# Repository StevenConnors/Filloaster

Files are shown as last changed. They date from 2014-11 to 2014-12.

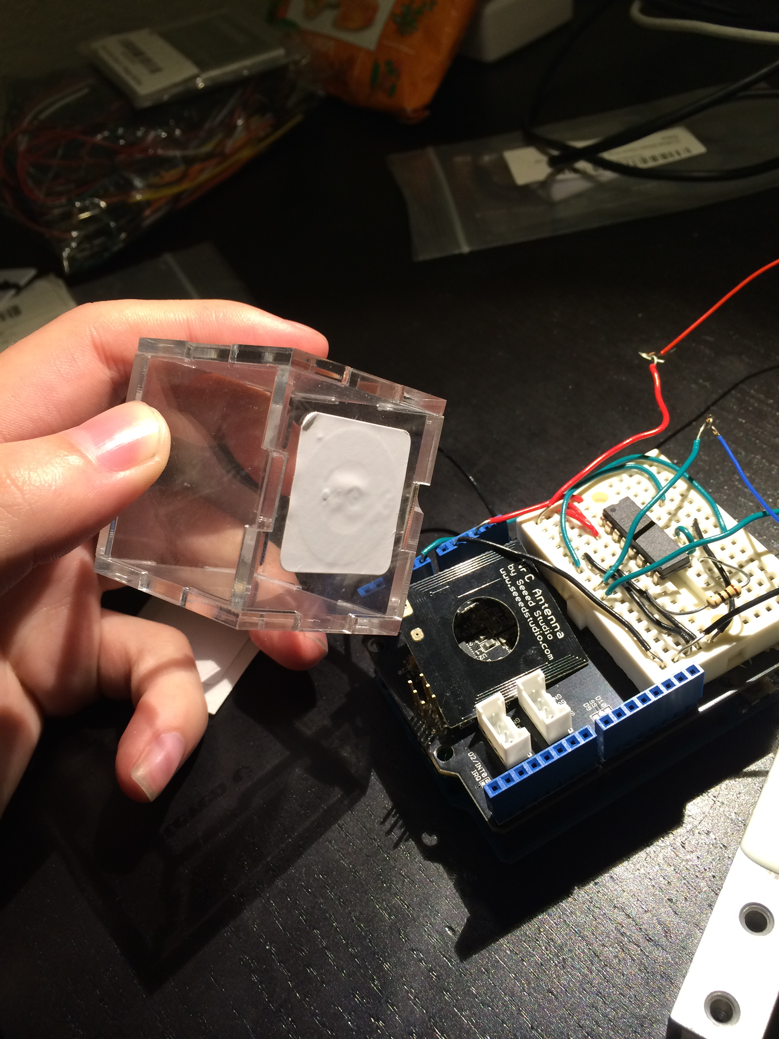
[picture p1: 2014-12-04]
Documents/Photos/prototype1.jpg

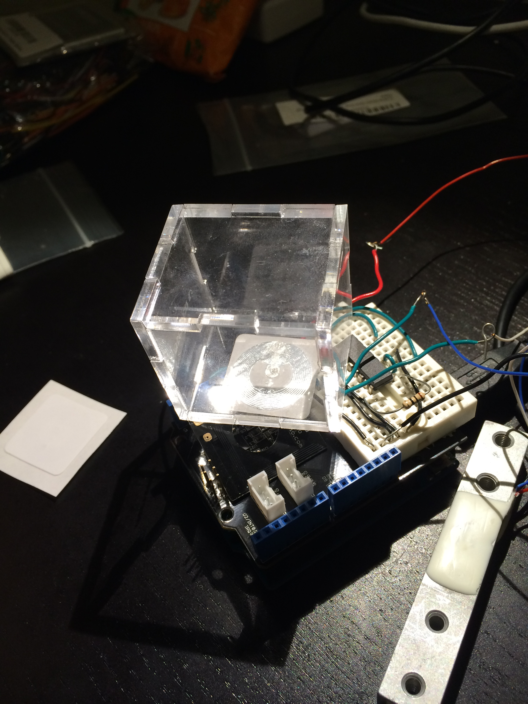
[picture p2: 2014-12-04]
Documents/Photos/IMG_3669.JPG

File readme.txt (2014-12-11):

Filloaster - A smart coaster that keeps you always filled.

Main website: steven77723.github.io/Filloaster

Concept:

List of Files and their Description:

Main Folder: Consists of various folders and files. The files are crucial to the
project as these initiate the Node server and execute the routing and the 
starting of web sockets for the browser and the Arduino. A detailed description
of each file can be found at the top of each file respectively. However, to give
a brief over view of how it works, the user calles index.js. Then index.js
creates a routing method for each url which is mapped to a file in the project
folder. Then server.js is called and run, where it creates sockets to the 
Arduino and the browser. Server.js handles all computationally heavy tasks while
the other folders send flags to signal such tasks.

Pages Folder: Mainly consists of html files which are used when deploying the 
server. However, there are three that we'd like to focus on. 

The first is the main html file, main.html. This file is the website that we
first displayed during the demo and we've placed a lot of emphasis on design. 
This page can be seen at steven77723.github.io/Filloaster. 

The second html file that needs emphasis is restaurant.html. We designed this
page so that it resembles a live restaurant with customers and seats. For the 
sake of the demo, we only displayed a change in color of seating with respect
to the state of the glass (needs refill / not). However, the color can also be
white if there is nobody at the table. This page uses SocketIO to receive the 
information obtained from the Filloaster (Arduino).

The most important page in terms of the demo is interface.html. This file allows
us to visually see the information sent via the Arduino, such as the amount of
liquid in the glass, the weight of the full / empty / current glass, the type of
drink that is in the glass, and the state of the Filloaster. 

ArduinoCode Folder: Has one file, filloster.ino that handles everything related
to the Arduino. This file receives information regarding the weight of the
glass, the state of Filloaster, the NFC information (glass type and phone 
number), and sends flags to server.js where more computationally heavy items are
executed. The code implements a simple finite state machine which makes the code
cleaner and easier to read and understand. 

Case Design: Initially we we're going to 3d print a casing for the Arduino for
aesthetics reasons, but due to the restriction that the force of the glass needs
to be pressed directly in the center of the we decided not to print it for the 
demo. However within this folder is the 3d model of the casing.

Documents: Included are the documents / images / slides for the demo. We've also
included a circuitry diagram which people can use if they would like to recreate
Filloaster with their own hands. 

Node_Modules Folder: Simply put, the modules we used: socketio, serial port, and
Twilio.

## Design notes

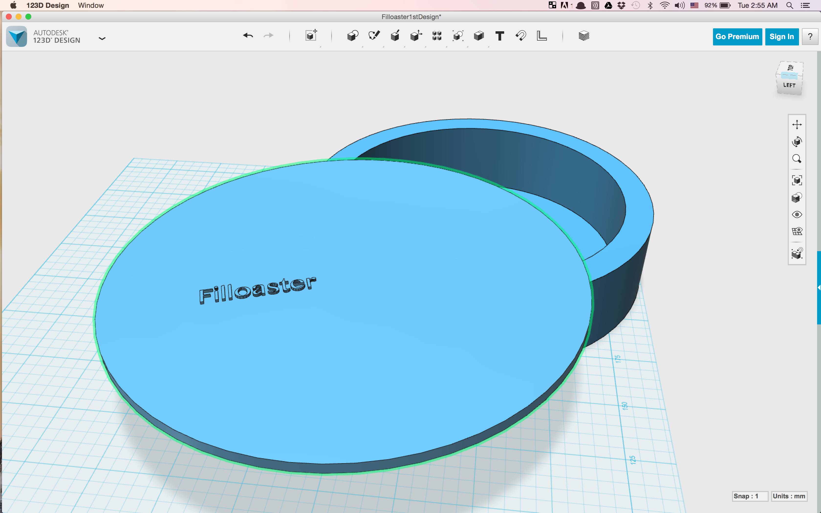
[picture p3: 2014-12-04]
Documents/Photos/filloasterdesign.png

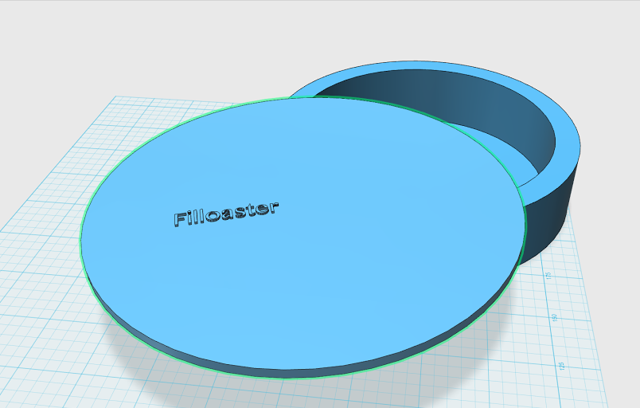
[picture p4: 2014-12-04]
bootstrap/img/filloasterdesign.png

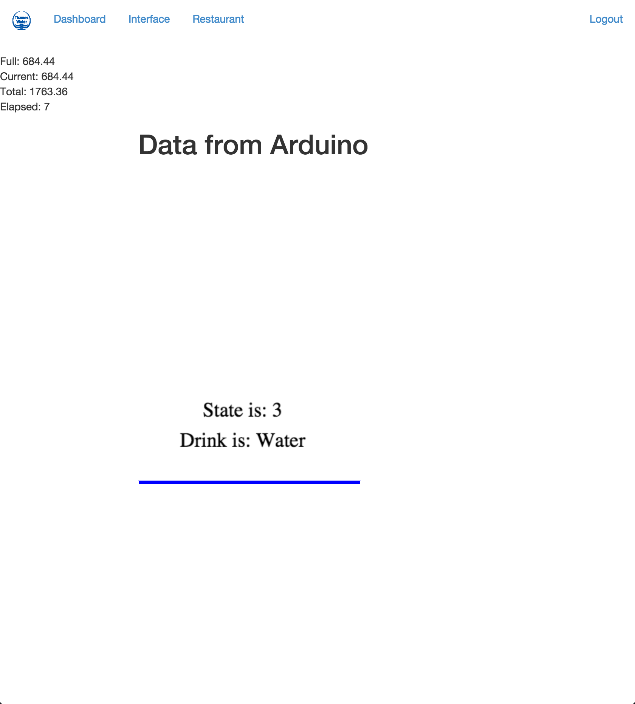
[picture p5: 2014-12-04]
Documents/Photos/Screen Shot 2014-12-03 at 12.55.47 AM.png

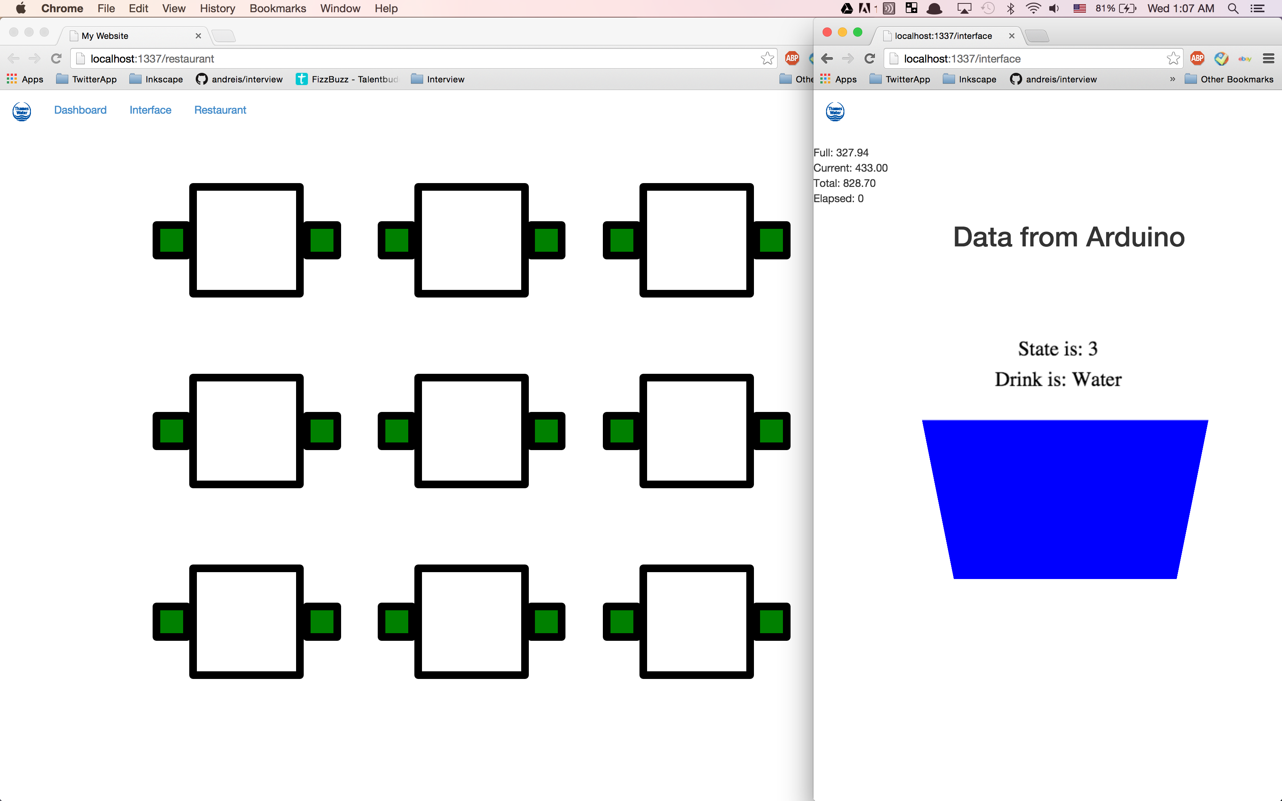
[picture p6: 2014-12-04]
Documents/Photos/Screen Shot 2014-12-03 at 1.07.37 AM.png

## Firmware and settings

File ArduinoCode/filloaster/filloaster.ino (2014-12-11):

#include <SPI.h>
#include <PN532_SPI.h>
#include "PN532.h"

//NFC things
PN532_SPI pn532spi(SPI, 10);
PN532 nfc(pn532spi);

// LED vars 
const int ledPin = 13;

// LED read vars
String inputString = "";         // a string to hold incoming data
boolean toggleComplete = false;  // whether the string is complete
char inChar;

// Potmeter vars
const int analogInPin = A1;
int sensorValue = 0;        // value read from the potmeter
int prevValue = 0;          // previous value from the potmeter

//load cell calibration
float loadA = 0.355; 
int analogvalA = 130; 
float loadB = 0.440; 
int analogvalB = 220; 
float analogValueAverage = 0;

//FSM for the system
int Filloaster_State = 0;
/*
If 0, then nothing is on it.
If 1, then glass is on it, get glass weight.
If 2, drink is being poured. If value stablizes, go to 3
If 3, Measure the total amount (glass + drink). If less than x go to 4
If 4, Then send signal to refill.
*/

//FSM for NFCs
int NFC_State = 0;
/*
If 0, then waiting for phone number
If 1, then halting for diff NFC
If 2, then waiting for type of drink
If 3, then not waiting.
*/


//Constants to measure liquid.
float noWeights = 15;
float glassWeight;
int glassConstant = 3; //magic number
float calibWeight = 0;
int calibCount = 0;
float sumOfCalibLoads = 0;
float fullGlass;
float currentGlass = 0;
int difference;
int magicNum = 60;
int numIterations = 50;
boolean noGlass = false;

//other constants
float amountDrunk = 0;
float totalAmountDrunk = 0;
float refillThreshold = 0.5;

//time Constants
unsigned long StartTime = 0;
unsigned long CurrentTime = 0;
unsigned long ElapsedTime = 0;
int leaveTime = 10;
int userLeft = 0;



void setup() {
  // initialize serial:
  Serial.begin(9600);
  // init LEDS
  pinMode(ledPin,OUTPUT);
  digitalWrite(ledPin,0);
  // init NFC modules
  nfc.begin();
  nfc.setPassiveActivationRetries(0xFF);
  nfc.SAMConfig();    
}


void loop() 
{
  boolean success;
  uint8_t uid[] = { 0, 0, 0, 0, 0, 0, 0 };  // Buffer to store the returned UID
  uint8_t uidLength;                        // Length of the UID 
  //Currently using a tag to mimick phone
  //tagData is 467F0A433D80
  if (NFC_State == 0)
  {
    getPhoneNumber(success, uid, uidLength);
  }
  //Have a delay period
  else if (NFC_State == 1)
  {
    delay(5000);
    NFC_State = 2;
  }
  //Get the type of drink
  else if (NFC_State == 2)
  {
    getGlassType(success, uid, uidLength);
    Filloaster_State = 1;
  }
  else if (NFC_State == 3)
  {
    senseorMeasurements();
  }
  delay(30); // give the Arduino some breathing room.

}

void getPhoneNumber(boolean success, uint8_t uid[], uint8_t uidLength){
  success = nfc.readPassiveTargetID(PN532_MIFARE_ISO14443A, &uid[0], &uidLength);
  if (success) 
  {
    Serial.print("P"); // begin character 
    for (uint8_t i=0; i < uidLength; i++) 
    {
      Serial.print(uid[i], HEX); 
    }
    Serial.print("H"); // end character
    NFC_State = 1;
    // Wait 1 second before continuing
  }
  else
  {
    // PN532 probably timed out waiting for a card
    //Serial.println("404");
  }
}

void getGlassType(boolean success, uint8_t uid[], uint8_t uidLength)
{
  success = nfc.readPassiveTargetID(PN532_MIFARE_ISO14443A, &uid[0], &uidLength);
  if (success) 
  {
    Serial.print("N"); // begin character 
    for (uint8_t i=0; i < uidLength; i++) 
    {
      Serial.print(uid[i], HEX); 
    }
    Serial.print("C"); // end character
    NFC_State = 3;
    // Wait 1 second before continuing
  }
  else
  {
    //Serial.println("404");
  }
}

void senseorMeasurements()
{
  //Deals with incoming messages
  receivedSignalFromNode();
  //Convert analog value to load (in mL)
  int analogValue = analogRead(0);
  analogValueAverage = 0.99*analogValueAverage + 0.01*analogValue;
  //float load = analogToLoad(analogValue) * 1000;
  float load = analogValue;
//

  sendValues();
  //Load is in mL

  // get the weight of the glass
  if (Filloaster_State == 1)
  {
    if (load > (glassConstant * noWeights))
    {
      glassWeight = load;
      Filloaster_State = 2;
    }
  }
  //get weight of water and glass
  else if (Filloaster_State == 2)
  {
    difference = 25;
    if (calibWeight - difference < load < calibWeight + difference) //magic number
    {
      calibCount++;
      sumOfCalibLoads = sumOfCalibLoads + load;
    }
    else
    {
      calibCount = 0;
      sumOfCalibLoads = 0;
    }
    //The value has been constant for 10 iterations
    if (calibCount == numIterations)
    {
      fullGlass = sumOfCalibLoads / numIterations;
      currentGlass = fullGlass;
      Filloaster_State = 3;
      calibCount = 0;
      sumOfCalibLoads = 0;
    }
    calibWeight = load;
  }
  //Glass is full now, now we measure amount in cup
  else if (Filloaster_State == 3)
  {
    if (load > currentGlass + magicNum) //magic number
    {
      totalAmountDrunk = totalAmountDrunk + amountDrunk;
      amountDrunk = 0;
      Filloaster_State = 2;
    }
    // make sure that we don't take the case when person is drinking
    if (!(load < glassWeight)) //means not currently drinking: cup is not in air
    {
      //////////////////////////////////////////////////////////////////////////////Check HERE
      currentGlass = load;
      amountDrunk = fullGlass - currentGlass;
      if (amountDrunk < 0) amountDrunk = 0;

      if (currentGlass < refillThreshold * fullGlass)
      {
        //Send signal to webserver to refill.
        Filloaster_State = 4;
      }
    }
  }
  // sent signal to waiter and waiting for response
  else if (Filloaster_State == 4)
  {
    //Code when the waiter refills it.
    //I should look over here. What if waiter picks glass up.
    if (load > currentGlass + magicNum) //magic number
    {
      totalAmountDrunk = totalAmountDrunk + amountDrunk;
      amountDrunk = 0;
      Filloaster_State = 2;
    }    
    if (!(load < glassWeight)) //means not currently drinking: cup is not in air
    {
      currentGlass = load;
      amountDrunk = fullGlass - currentGlass;
      if (amountDrunk < 0) amountDrunk = 0;    
    }
    //Code to receive signal from webserver and to modify refillThreshold
    //Then jump to State 3
  }

  //In a separate section, check if the customer left by checking the value
  //of load and comparing it to if filloaster empty or not. Use 10 seconds.
  //Then send a message to the phone it was assigned to.
  sensorValue = analogRead(analogInPin);  
  checkDone(load);
}


void checkDone(float load){
  /*filloaster state must be >=2
  have a bool so that for the first time its 0, startTime.
  Otherwize look at CurrentTime and Elapsed.
  If not 0, then turn bool off. and Reset
unsigned long StartTime = millis();

unsigned long CurrentTime = millis();
unsigned long ElapsedTime = CurrentTime - StartTime;
  */
  if (Filloaster_State == 1) return;
  
  //first time there no glass
  if (!(noGlass)){
    if (load < (glassConstant * noWeights)){
      StartTime = millis();
      noGlass = true;
    }
  }
  //not first time
  else{
    CurrentTime = millis();
    ElapsedTime = CurrentTime - StartTime;
    if (ElapsedTime > leaveTime*1000)
    {
      userLeft = 1;
      sendValues();
    }
    if (load >= (glassConstant * noWeights)){
      StartTime = 0;
      noGlass = false;
      CurrentTime = 0;
      ElapsedTime = 0;
    }
  }
}

//Converts AnalogValue to an actual weight.
float analogToLoad(float analogval){
  float load = mapfloat(analogval, analogvalA, analogvalB, loadA, loadB);
  return load;
}
//Map function for float
float mapfloat(float x, float i_min, float in_max, float out_min, float out_max)
{
  return (x - i_min) * (out_max - out_min) / (in_max - i_min) + out_min;
}

//CHIJKMNOPQVWXYZ
void sendValues(){
  //state of filloaster
  Serial.print("S");
  Serial.print(Filloaster_State);
  Serial.print("D");
  //amount in current glass
  Serial.print("G");      
  Serial.print(currentGlass); 
  Serial.print("L");
  //amount in a "full glass"
  Serial.print("F");      
  Serial.print(fullGlass); 
  Serial.print("U");
  //Total amount user drank
  Serial.print("T");      
  Serial.print(totalAmountDrunk); 
  Serial.print("A");
  //User left or not
  Serial.print("U");
  Serial.print(userLeft);
  Serial.print("R");

  Serial.print("C");
  Serial.print(ElapsedTime/1000); // in terms of seconds
  Serial.print("H");

  Serial.print("\n");
// Value of Potmeter
  Serial.print("B"); // begin character 
  //Serial.print((int)load); Not fully accurate 
  Serial.print(sensorValue); 
  Serial.print("E"); // end character
}

void receivedSignalFromNode()
{
  // Recieve data from Node and write it to a String
  while (Serial.available() && toggleComplete == false) 
  {
    inChar = (char)Serial.read();
    if(inChar == 'E')
    { // end character for led
      toggleComplete = true;
    }
    else
    {
      inputString += inChar; 
    }
  }
  // Toggle LED 13
  if(!Serial.available() && toggleComplete == true)
  {
    toggling();
  }
}

void toggling()
{
  // convert String to int. 
  int recievedVal = stringToInt();
  
  if(recievedVal == 0)
  {
    digitalWrite(ledPin,recievedVal);
  }
  else if(recievedVal == 1)
  {
    digitalWrite(ledPin,recievedVal);
  }    
  toggleComplete = false;
}

int stringToInt()
{
    char charHolder[inputString.length()+1];
    inputString.toCharArray(charHolder,inputString.length()+1);
    inputString = "";
    int _recievedVal = atoi(charHolder);
    return _recievedVal;
}

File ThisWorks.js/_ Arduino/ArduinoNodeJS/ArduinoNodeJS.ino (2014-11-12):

#include "SPI.h"
#include "PN532_SPI.h"
#include "snep.h"
#include "NdefMessage.h"

//NFC Constants
PN532_SPI pn532spi(SPI, 10);
SNEP nfc(pn532spi);
uint8_t ndefBuf[128];
//NFC Vars
String drinkType = "";

// LED vars 
const int ledPin = 13;

// LED read vars
String inputString = "";         // a string to hold incoming data
boolean toggleComplete = false;  // whether the string is complete
char inChar;

// Potmeter vars
const int analogInPin = A0;
int sensorValue = 0;        // value read from the potmeter
int prevValue = 0;          // previous value from the potmeter

//load cell calibration
float loadA = 0.355; 
int analogvalA = 130; 
float loadB = 0.440; 
int analogvalB = 220; 
float analogValueAverage = 0;

//FSM for the system
int Filloaster_State = 0;

//Constants to measure liquid.
float noWeights;
float glassWeight;
int glassConstant = 3; //magic number
float calibWeight = 0;
int calibCount = 0;
float sumOfCalibLoads = 0;
float fullGlass;
float currentGlass = 0;

//other constants
float amountDrunk = 0;
float totalAmountDrunk = 0;
float refillThreshold = 0.5;



void setup() {
  // initialize serial:
  Serial.begin(9600);
  // init LEDS
  pinMode(ledPin,OUTPUT);
  digitalWrite(ledPin,0);
}


void loop() 
{
   // Recieve data from Node and write it to a String
   while (Serial.available() && toggleComplete == false) 
   {
    inChar = (char)Serial.read();
    if(inChar == 'E')
    { // end character for led
     toggleComplete = true;
    }
    else
    {
      inputString += inChar; 
    }
  }
  // Toggle LED 13
  if(!Serial.available() && toggleComplete == true)
  {
    toggling();
  }
  int analogValue = analogRead(0);
  analogValueAverage = 0.99*analogValueAverage + 0.01*analogValue;
  float load = analogToLoad(analogValue) * 1000;
  //Load is in mL
  Serial.print("S");
  Serial.print(Filloaster_State);
  Serial.print("D");
  //Value without anything
  if (Filloaster_State == 0)
  {
    if ((10 < analogValueAverage) || (analogValueAverage < 20)) //magic number
    {
        ///////////////////////////////////////////////////////////////////////////////////////////
      if (Filloaster_State == 0 || Filloaster_State == 1 || Filloaster_State == 2)
      {
        Serial.println("Waiting for message from Peer");
        int msgSize = nfc.read(ndefBuf, sizeof(ndefBuf));
        if (msgSize > 0) 
        {
            NdefMessage msg  = NdefMessage(ndefBuf, msgSize);
            //msg.print();
                
            NdefRecord record = msg.getRecord(0);

            int payloadLength = record.getPayloadLength();
            byte payload[payloadLength];
            record.getPayload(payload);        
            
            // The TNF and Type are used to determine how your application processes the payload
            // There's no generic processing for the payload, it's returned as a byte[]
            int startChar = 0;        
            if (record.getTnf() == TNF_WELL_KNOWN && record.getType() == "T") 
            { // text message
              // skip the language code
              startChar = payload[0] + 1;
            } 
            else if (record.getTnf() == TNF_WELL_KNOWN && record.getType() == "U") 
            { // URI
              // skip the url prefix (future versions should decode)
              startChar = 1;
            }
            // Force the data into a String (might fail for some content)
            // Real code should use smarter processing
            String payloadAsString = "";
            for (int c = startChar; c < payloadLength; c++) 
            {
              payloadAsString += (char)payload[c];
            }
            Serial.println(payloadAsString);
            
            //if these strings are equal then change drinks, or color
            Serial.print("N");
            if (payloadAsString == "speech.cs.cmu.edu/coinlab/")
            {
              Serial.println("Coke!");
              noWeights = load;
              Filloaster_State = 1;            
            }
            else if (payloadAsString == "cs.cmu.edu/~anatoleg/")
            {
              Serial.println("Lemonade");
              noWeights = load;
              Filloaster_State = 1;              
            }
            else if (payloadAsString == "cs.cmu.edu/~awb/")
            {
              Serial.println("Water");
              noWeights = load;
              Filloaster_State = 1;
            }
            else if (payloadAsString == "cs.cmu.edu/")
            {
              Serial.println("Russian Water");
              noWeights = load;
              Filloaster_State = 1;
            }
            Serial.print("C");

            Serial.println("\nSuccess");
        }  
      }
    }
  }
  // get the weight of the glass
  else if (Filloaster_State == 1)
  {
    if (load > (glassConstant * noWeights))
    {
      glassWeight = load;
      //Have the NFC code to read the tag on the glass which identifies the 
      //Drink
      Filloaster_State = 2;
    }
  }
  //get weight of water and glass
  else if (Filloaster_State == 2)
  {
    if (calibWeight - 10  <load < calibWeight +10) //magic number
    {
      calibCount++;
      sumOfCalibLoads = sumOfCalibLoads + load;
    }
    else
    {
      calibCount = 0;
      sumOfCalibLoads = 0;
    }
    //The value has been constant for 20 iterations
    if (calibCount == 20)
    {
      fullGlass = sumOfCalibLoads / 10;
      currentGlass = sumOfCalibLoads / 10;
      Filloaster_State = 3;
    }
    calibWeight = load;
  }
  //Glass is full now, now we measure amount in cup
  else if (Filloaster_State == 3)
  {
    if (load > currentGlass + 10) //magic number
    {
      totalAmountDrunk = totalAmountDrunk + amountDrunk;
      amountDrunk = 0;
      Filloaster_State = 2;
    }
    // make sure that we don't take the case when person is drinking
    if (!(load < glassWeight)) //means not currently drinking: cup is not in air
    {
      currentGlass = load;
      amountDrunk = fullGlass - currentGlass;
      if (currentGlass < refillThreshold * fullGlass)
      {
        //Send signal to webserver to refill.
        Filloaster_State = 4;
      }
    }
  }
  // sent signal to waiter and waiting for response
  else if (Filloaster_State == 4)
  {
    //Code when the waiter refills it.
    //I should look over here. What if waiter picks glass up.
    if (load > currentGlass + 10) //magic number
    {
      totalAmountDrunk = totalAmountDrunk + amountDrunk;
      amountDrunk = 0;
      Filloaster_State = 2;
    }    
    if (!(load < glassWeight)) //means not currently drinking: cup is not in air
    {
      currentGlass = load;
      amountDrunk = fullGlass - currentGlass;
    }
    //Code to receive signal from webserver and to modify refillThreshold
    //Then jump to State 3
  } 

  // Potmeter
   sensorValue = analogRead(analogInPin);
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

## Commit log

2014-11-20 added alyssa’s web design
2014-11-21 Socketio fully working. I’m going to implement changing colors now.
2014-12-03 still can’t fix that bug with nfc and load cell
    [server.js]
2014-12-03 added a lot of routes for alyssa’s code
2014-12-04 Included Filloaster diagram
    [Filloaster.fzz]
